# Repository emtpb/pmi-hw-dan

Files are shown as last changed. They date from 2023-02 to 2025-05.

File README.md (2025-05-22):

# PMI-DAN (Diodes And NMOS)

This pcb is designed for the course PMI (Practical course Microcontroller and Interface electronics). It features four LEDs and four open-drain NMOSFETs. It can be chained with [PMI-CARLOS](https://github.com/emtpb/pmi-hw-carlos) (thus only four of the available eight GPIO pins are used).

Pin header and sockets are compatible with
[Digilents Pmod](https://digilent.com/reference/pmod/start) interface.

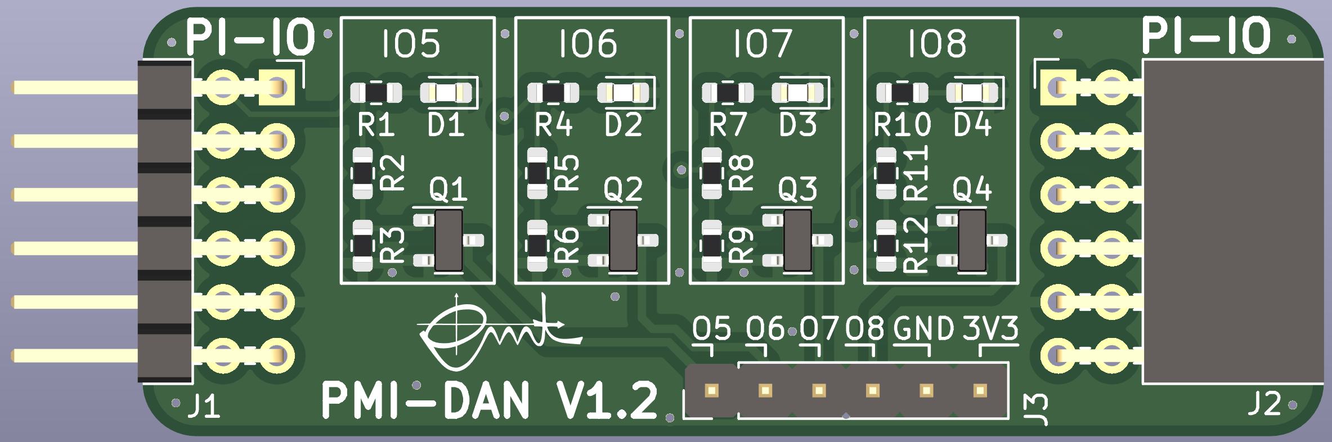
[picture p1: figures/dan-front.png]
DAN-front


The board can be used with [PMI-BOB2](https://github.com/emtpb/pmi-hw-bob2)
pcb.

# Interactive BOM

An interactive html BOM page with pcb layout and material placement can be found [here](https://emtpb.github.io/pmi-hw-dan/bom/ibom.html).

# Changelog

## 1.0
* First prototype

## 1.1
* First release

## 1.2
* Convert project to Kicad 6
* Round pcb corners
* Place output labeling above pin header

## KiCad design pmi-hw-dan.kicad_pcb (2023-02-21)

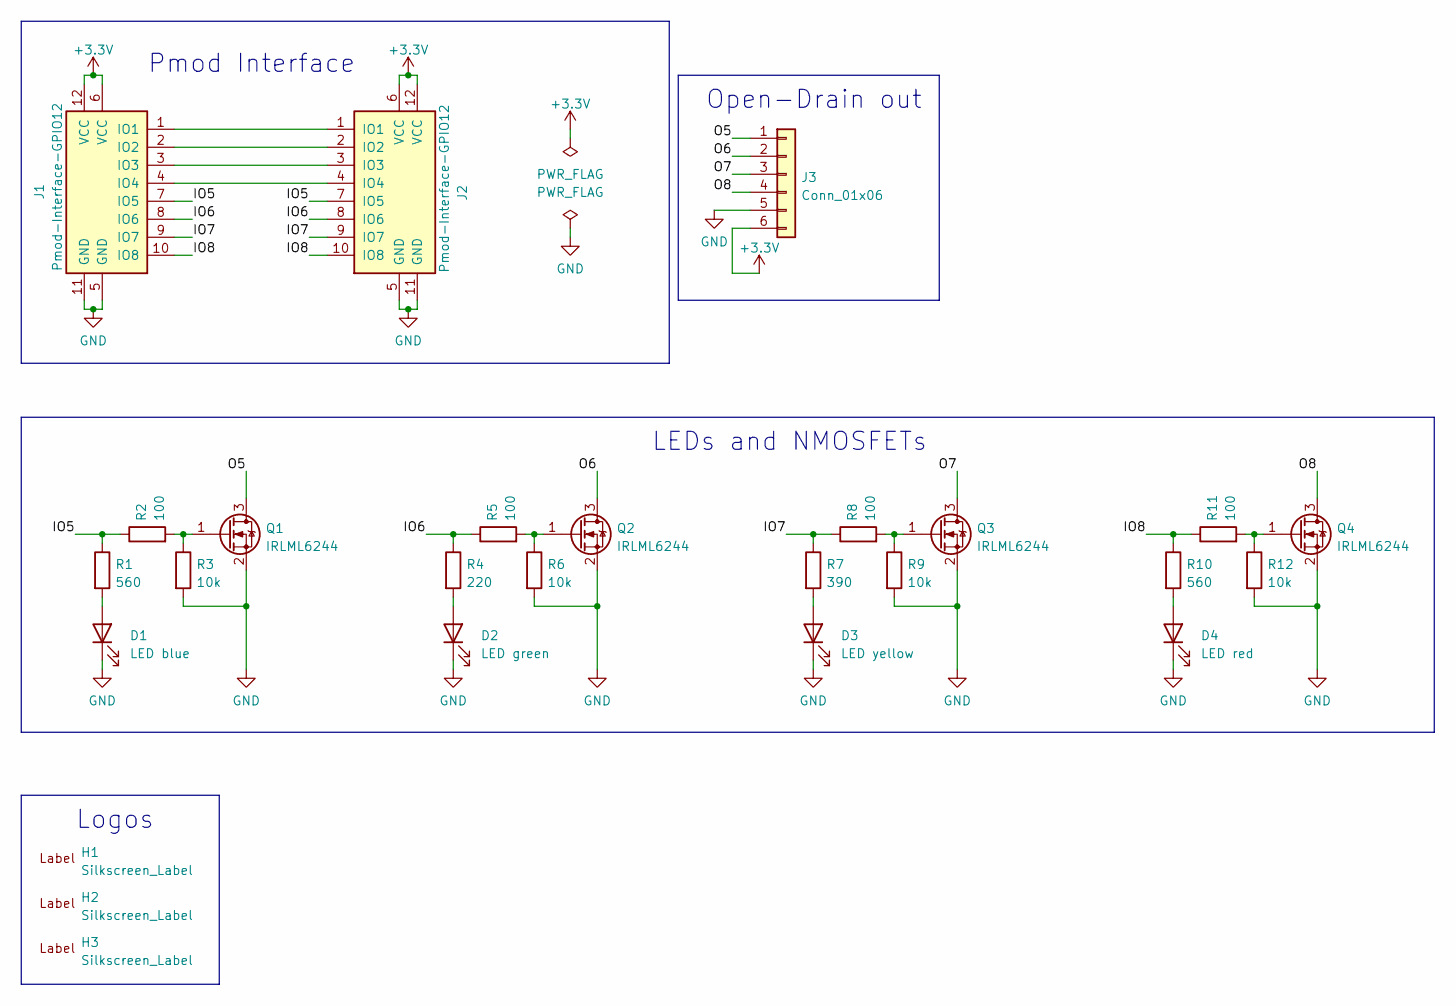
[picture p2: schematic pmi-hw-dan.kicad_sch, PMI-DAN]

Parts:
D1: LED blue; LED_0603_1608Metric; Manufacturer Part No LB Q39G-L2OO-35-1; Mouser Part No 720-LBQ39GL2N2351
D2: LED green; LED_0603_1608Metric; Manufacturer Part No LG Q396-PS-35; Digikey Part No 475-3754-1-ND
D3: LED yellow; LED_0603_1608Metric; Manufacturer Part No LY Q396-P1Q2-36; Digikey Part No 475-3467-1-ND
D4: LED red; LED_0603_1608Metric; Manufacturer Part No LS Q976-NR-1-0-20-R18; Digikey Part No 475-2512-1-ND
H1: Silkscreen_Label; UPB-Logo_En_12.3X4.3mm
H2, H3: Silkscreen_Label; EMT-Logo_8.2x4.1mm_Silkscreen
J1: Pmod-Interface-GPIO12; Pmod_Interface_Male12
J2: Pmod-Interface-GPIO12; Pmod_Interface_Female12
J3: Conn_01x06; PinHeader_1x06_P2.54mm_Vertical
Q1, Q2, Q3: IRLML6244; SOT-23
Q4: IRLML6244; SOT-23; Manufacturer Part No IRLML6244TRPBF; Digikey Part No IRLML6244TRPBFCT-ND
R1, R10: 560; R_0603_1608Metric
R2, R5, R8, R11: 100; R_0603_1608Metric
R3, R6, R9, R12: 10k; R_0603_1608Metric
R4: 220; R_0603_1608Metric
R7: 390; R_0603_1608Metric

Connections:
+3.3V: J1.6 (VCC), J1.12 (VCC), J2.6 (VCC), J2.12 (VCC), J3.6
/IO5: J1.7 (IO5), J2.7 (IO5), R1.1, R2.1
/IO6: J1.8 (IO6), J2.8 (IO6), R4.1, R5.1
/IO7: J1.9 (IO7), J2.9 (IO7), R7.1, R8.1
/IO8: J1.10 (IO8), J2.10 (IO8), R10.1, R11.1
/O5: J3.1, Q1.3 (D)
/O6: J3.2, Q2.3 (D)
/O7: J3.3, Q3.3 (D)
/O8: J3.4, Q4.3 (D)
GND: D1.1 (K), D2.1 (K), D3.1 (K), D4.1 (K), J1.5 (GND), J1.11 (GND), J2.5 (GND), J2.11 (GND), J3.5, Q1.2 (S), Q2.2 (S), Q3.2 (S), Q4.2 (S), R3.2, R6.2, R9.2, R12.2
unnamed: D1.2 (A), R1.2
unnamed: D2.2 (A), R4.2
unnamed: D3.2 (A), R7.2
unnamed: D4.2 (A), R10.2
unnamed: J1.1 (IO1), J2.1 (IO1)
unnamed: J1.2 (IO2), J2.2 (IO2)
unnamed: J1.3 (IO3), J2.3 (IO3)
unnamed: J1.4 (IO4), J2.4 (IO4)
unnamed: Q1.1 (G), R2.2, R3.1
unnamed: Q2.1 (G), R5.2, R6.1
unnamed: Q3.1 (G), R8.2, R9.1
unnamed: Q4.1 (G), R11.2, R12.1

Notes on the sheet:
Open-Drain out
Pmod Interface
LEDs and NMOSFETs
Logos

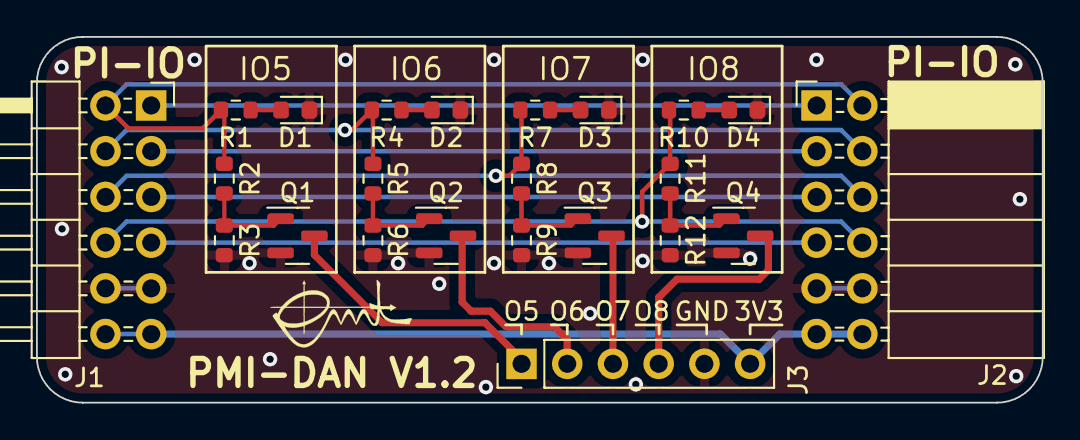
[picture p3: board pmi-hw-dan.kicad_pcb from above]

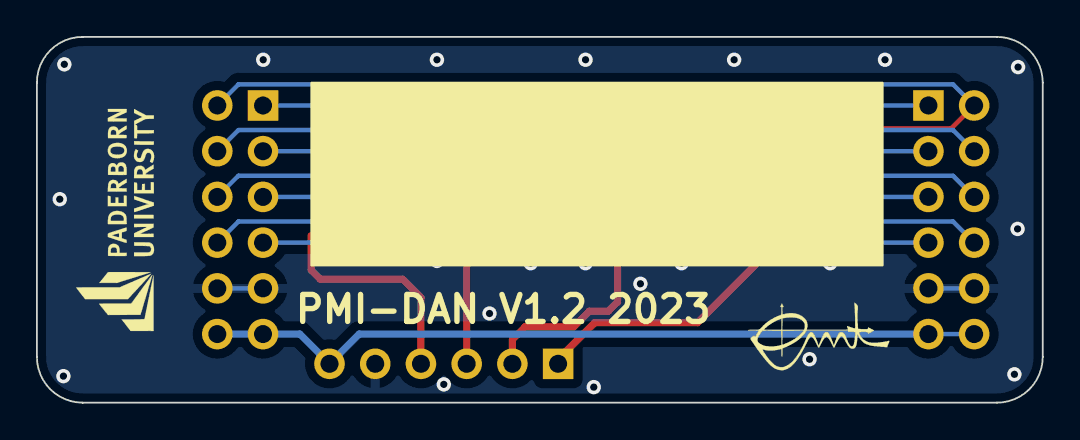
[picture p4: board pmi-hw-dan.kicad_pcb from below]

Board: 2 copper layers, 55.9 x 20.3 mm, 26 parts (2 on the bottom side), 22 nets.

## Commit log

2022-09-02 Add project files
    [pmi-hw-dan.kicad_pcb, pmi-hw-dan.kicad_sch]
2023-02-21 Bump to version 1.2
    [pmi-hw-dan.kicad_pcb, pmi-hw-dan.kicad_sch]
2025-05-22 Add interactive BOM link
